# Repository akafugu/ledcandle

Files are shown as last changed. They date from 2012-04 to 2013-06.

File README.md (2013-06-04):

LED Candle Firmware & CAD files
--------------------------

Firmware and CAD filesfor the [Akafugu Flickering LED Candle](http://www.akafugu.jp/posts/products/ledcandle/)

The Akafugu LED Candle is an artificial candle that imitates the flickering of
a real candle. Use it in place of a real tea candle: It will fit
inside a tea candle casing or any holder made for tea candles.

It comes as a kit of easy to solder components, and is suitable for beginners
to soldering.

FEATURES:

* Randomly flickering LED: Imitates a candle
* Fits inside a tea candle casing
* Open Source Firmware (available at [GitHub](https://github.com/akafugu/ledcandle))
* Open Source Hardware: Eagle PCB design files available at GitHub.
* On-board ISP header for upgrading firmware

Firmware
--------

The Akafugu LED Candle uses an ATTiny13A microcontroller. The firmware is written for the
avr-gcc compiler.

See [here](http://www.akafugu.jp/posts/resources/avr-gcc/) for avr-gcc installation instructions.

Plug in ISP programmer into the ISP header, and in the directory 'firmware', do:

make fuse flash

An alternative firmware is available in the directory firmware_pwm, courtesy of madworm.
This firmware features a very different and slower flickering style.

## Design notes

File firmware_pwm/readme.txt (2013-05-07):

Works very well with the akafugu LED candle board.

Notes:
======

The FUSE settings of the AVR are different to the original from akafugu.
Probably as a consequence of the increased clock-speed of the internal
RC-oscillator, the AVR won't start after programming when using 5V.
It will run fine with 3.3V or the lithium battery.

This issue can be addressed in two ways:

* switch your ISP programmer to 3.3V
* add a small bypassing capacitor right across pins #4 and #8

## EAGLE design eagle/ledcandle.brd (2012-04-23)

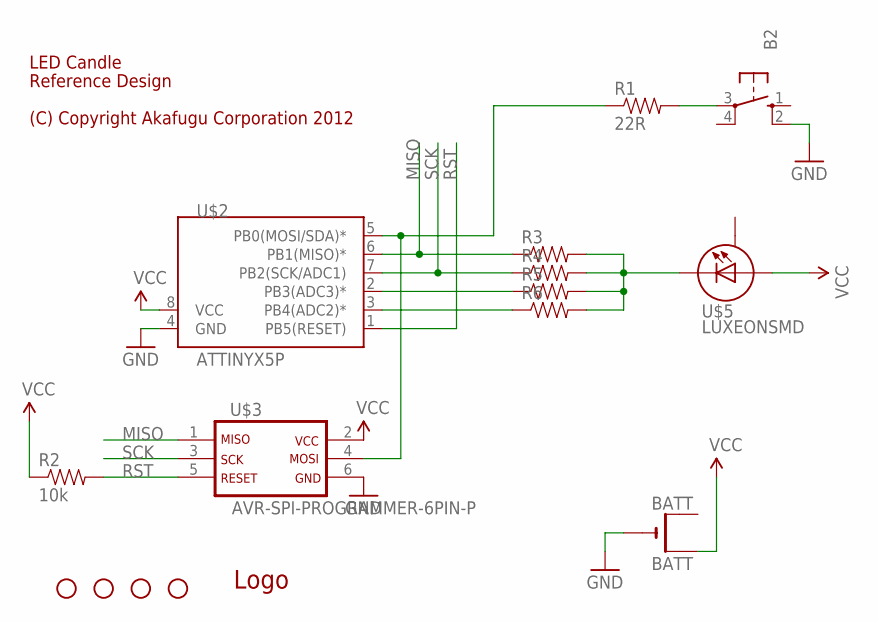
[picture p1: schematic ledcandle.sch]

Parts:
B2: 10-XX; B3F-10XX
BATT: BATT; CR2032-THM-PAD
JP1, JP2, JP3, JP4: STAND-OFF
R1: 22R; 1/6W-RES-OUTLINE
R2: 10k; 1/6W-RES-OUTLINE
R3, R4, R5, R6: RESISTOR-PTH-1/6W-OUTLINE; 1/6W-RES-OUTLINE
U$1: OSHW-LOGO-FILL
U$2: ATTINYX5P; DIL-8
U$3: AVR-SPI-PROGRAMMER-6PIN-P; 2X03
U$5: LUXEONSMD; LUXEON

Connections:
GND: B2.2 (S1), BATT.-, U$2.4 (GND), U$3.6
MISO: R3.1, U$2.6 (PB1(MISO)*), U$3.1
unnamed: R6.1, U$2.3 (PB4(ADC2)*)
unnamed: R3.2, R4.2, R5.2, R6.2, U$5.C
unnamed: R5.1, U$2.2 (PB3(ADC3)*)
unnamed: R1.1, U$2.5 (PB0(MOSI/SDA)*), U$3.4
RESET: B2.3, R1.2
RST: R2.2, U$2.1 (PB5(RESET)), U$3.5
SCK: R4.1, U$2.7 (PB2(SCK/ADC1)), U$3.3
VCC: BATT.+2 (+1), R2.1, U$2.8 (VCC), U$3.2, U$5.A

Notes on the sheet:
LED Candle
Reference Design
(C) Copyright Akafugu Corporation 2012

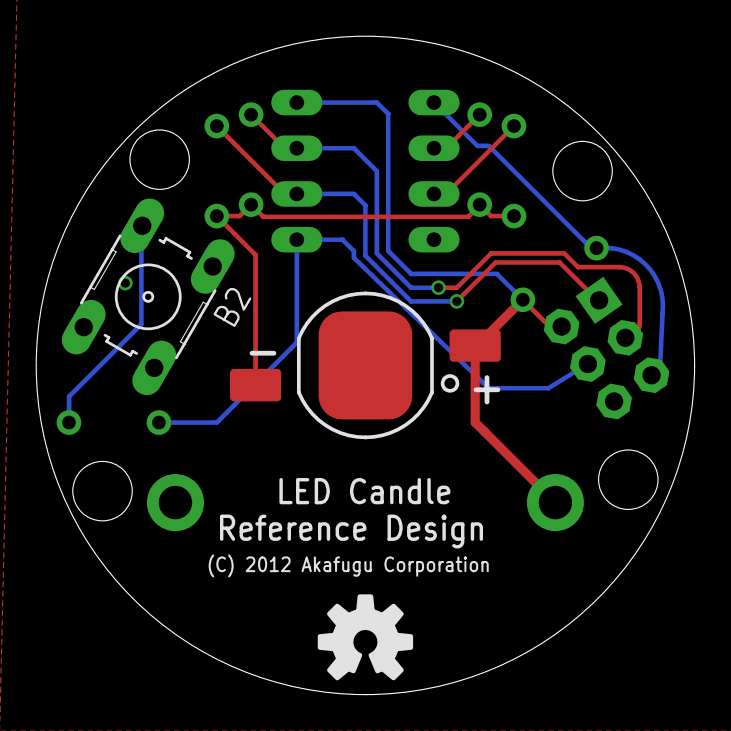
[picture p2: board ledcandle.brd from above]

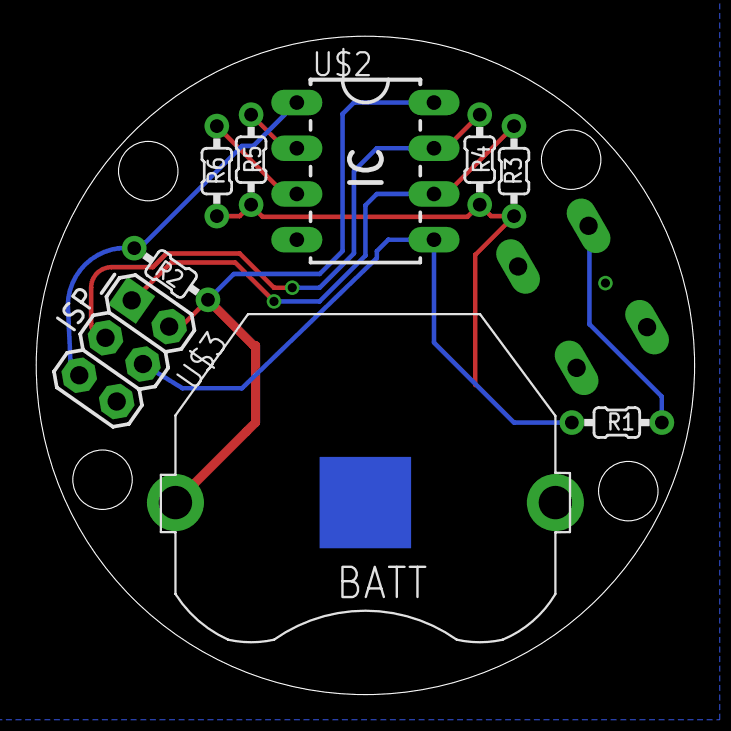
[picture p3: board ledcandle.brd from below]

Board: 2 copper layers, 36.6 x 36.6 mm, 16 parts (9 on the bottom side), 10 nets.

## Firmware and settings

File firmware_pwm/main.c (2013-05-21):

/*
 * Original firmware
 * =================
 *
 * Flickering LED Candle
 * (C) 2012 Akafugu Corporation
 *
 *
 * Alternative firmware with 8-bit PWM
 * ===================================
 *
 * 2013 - Robert Spitzenpfeil
 *
 *
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
 */

/*
 * Pinout:
 * PB0 (pin 5) - Button (INT0 interrupt)
 * PB1 (pin 6) - LED (PWM)
 * PB2 (pin 7) - LED
 * PB3 (pin 2) - LED
 * PB4 (pin 3) - LED
 * PB5 (pin 1) - Reset
 *
 * 1k resistor per pin. Suitable for running from a 3V CR2032 cell
 *
 *
 * Inspired by similar LED candle projects on Instructables:
 *
 * http://www.instructables.com/id/YAFLC-Yet-Another-Flickering-LED-Candle/
 * http://www.instructables.com/id/Realistic-Fire-Effect-with-Arduino-and-LEDs/
 *
 */

//#define DEBUG

#include <avr/io.h>
#include <avr/interrupt.h>
#include <avr/sleep.h>
#include <util/delay.h>
#include <stdbool.h>
#include "main.h"

// how long to stay on
uint16_t off_timer = ON_2H;

// minimum light-level
#define MIN_BRIGHTNESS 16

// random number seed (will give same flicker sequence each time)
uint32_t lfsr = 0xbeefcace;

volatile uint8_t brightness = 0; // not changed in an ISR, but prevent optimizer to throw it out
volatile uint8_t sleep_requested = 0;

int main(void)
{
	// Attiny13A fuse setting: -U lfuse:w:0x7A:m -U hfuse:w:0xFB:m
	//
	// set system-clock prescaler to 1/8
	// 4.8MHz RC-oscillator --> 600kHz system-clock
	CLKPR = _BV(CLKPCE);
	CLKPR = _BV(CLKPS1) | _BV(CLKPS0);

	// configure TIMER0
	TCCR0A = _BV(WGM01);	// set CTC mode
	TCCR0B = ( _BV(CS01) );	// set prescaler to 8
	// enable COMPA ISR
	TIMSK0 = _BV(OCIE0A);
	// set top value for TCNT0
	OCR0A = 10;		// just some start value

	// pull-up on for BUTTON_PIN
	PORT_OUT_REG |= _BV(BUTTON_PIN);
	// set port directions
	PORT_DIR_REG = PORT_DIR_MASK;
	
	// disable analog comparator to save power
	ACSR = _BV(ACD);

	// Pin change interrupt enabled
	// The actual pin will be activated later
	GIMSK |= _BV(PCIE);
		
	// globally enable interrupts
	// necessary to wake up from sleep via pin-change interrupt
	sei();

	fade(0,255,1);

	while (1) {
		// the flag 'sleep_requested' is set in the ISR: TIM0_COMPA_vect
		if(sleep_requested == 1) {
			do_sleep();
		}
		flicker();
	}
}

uint32_t rand(void)
{
	// http://en.wikipedia.org/wiki/Linear_feedback_shift_register
	// Galois LFSR: taps: 32 31 29 1; characteristic polynomial: x^32 + x^31 + x^29 + x + 1 
	lfsr = (lfsr >> 1) ^ (-(lfsr & 1u) & 0xD0000001u);
	return lfsr;
}

// Enter sleep mode: Wake on INT0 interrupt
void do_sleep(void)
{
	cli(); // turn all interrupts off, so we can be sure nothing gets disturbed here
	sleep_requested = 0;

	// now we want to make sure the button is not pressed and is stable (not bouncing)
	// switch bouncing is an unwanted wake-up source

	#ifdef DEBUG
		PORT_OUT_REG |= LED_MASK; // all ON - current source
	#else
		PORT_OUT_REG &= ~LED_MASK; // all ON - current sink
	#endif

	while( !(PORT_IN_REG & _BV(BUTTON_PIN)) ) { // while button is pressed (LOW)
		delay(500);
	}

	set_sleep_mode(SLEEP_MODE_PWR_DOWN);
	sleep_enable();

	sei();
	fade(255,0,1); // fade OUT after the button was released
	GIFR &= ~_BV(PCIF); // clear PC-interrupt flag - just to be safe
	PCMSK = PINC_MASK; // 'remove the safety' on the pin-change interrupt at the last possible moment
	sleep_cpu();
	sleep_disable();
	fade(0,255,1);	// wake up here again
}

// Interrupt signal PCINT0: On PB0 (PB2 for DEBUG, different board)
ISR(PCINT0_vect)
{
	PCMSK = 0; // clear PCINT-mask to disable pin-change interrupt
	GIFR |= _BV(PCIF); // clear PCIF
}

// Flicker by randomly setting pins PB1~PB4 on and off
void flicker(void)
{
	uint8_t flicker_brightness = (uint8_t)(rand()); // user lowermost 8 bits to set values for the LED brightness

	fade(brightness, MIN_BRIGHTNESS, (uint8_t)(rand() >> 30) ); // fade from current brightness down to MIN_BRIGHTNESS, random fade speed
	delay( (uint8_t)(rand() >> 24) ); // random delay
	fade(MIN_BRIGHTNESS, flicker_brightness, (uint8_t)(rand() >> 30) ); // fade from MIN_BRIGHTNESS to a random brightness, random fade speed
	delay( (uint8_t)(rand() >> 24) ); // random delay
}

ISR(TIM0_COMPA_vect)
{
	static uint16_t bitmask = 0b0000000000000001;
	static uint16_t sec_counter = 0;
	static uint16_t PWM_cycle_counter = 0;
	static uint16_t button_held_counter = 0;
	uint8_t OCR0A_next;

	// increase system-clock
	CLKPR = _BV(CLKPCE);	// set CLocK Prescaler Change Enable bit
	CLKPR = 0;		// set system-clock prescaler to 1 --> full 9.6MHz

	// Binary-weighted PWM generation - BEGIN

	if ( brightness & bitmask ) { // turn ON
		#ifdef DEBUG
			PORT_OUT_REG |= LED_MASK; // source current
		#else
			PORT_OUT_REG &= ~LED_MASK; // sink current
		#endif
	} else { // turn OFF
		#ifdef DEBUG
			PORT_OUT_REG &= ~LED_MASK;
		#else
			PORT_OUT_REG |= LED_MASK;
		#endif
	}

	OCR0A_next = bitmask; // the bitmask determines when the ISR is called next - intervals: 1, 2, 4, 8, 16, 32, 64, 128
	bitmask = bitmask << 1; // shift 1 bit to the left

	if (bitmask == _BV(9)) {
		bitmask = 0x0001;
		OCR0A_next = 2;
		PWM_cycle_counter++;
	}

	OCR0A = OCR0A_next;	// when to run next time
	TCNT0 = 0;		// clear timer to compensate for code runtime above
	TIFR0 = _BV(OCF0A);	// clear interrupt flag to kill any erroneously pending interrupt in the queue

	// PWM generation - END

	if (PWM_cycle_counter == 293) {	// count seconds
		sec_counter++;
		PWM_cycle_counter = 0;
	}

	if (PORT_IN_REG & _BV(BUTTON_PIN)) {	// button is not held
		button_held_counter = 0;
	} else {		// button is held
		button_held_counter++;
	}

	// time to go to sleep?
	if (off_timer != 0 && sec_counter >= off_timer) {
		sec_counter = 0;
		sleep_requested = 1;
	}
	// holding the button for 3 seconds turns the device off
	if (button_held_counter == 7032) {
		sec_counter = 0;
		sleep_requested = 1;
	}

	// decrease system-clock
	CLKPR = _BV(CLKPCE); // set 'CLocK Prescaler Change Enable'
	CLKPR = _BV(CLKPS1) | _BV(CLKPS0);	// set system-clock prescaler to 1/8 --> 4.8 MHz / 8 = 600kHz
}

void delay(uint16_t ms) {
	while(ms) {
		_delay_ms(1); // this function must be called with a compile-time CONST, otherwise it pulls in float-math (huge)
		ms--;
	}
}

void fade(uint8_t from, uint8_t to, uint8_t f_delay) {
	uint8_t counter;

	// I know the fade stops at (to-1).

	if(from <= to) {
		for(counter = from; counter < to; counter++) {
			brightness = counter;
			delay(f_delay);
		}
	}

	if(from > to) {
		for(counter = from; counter > to; counter--) {
			brightness = counter;
			delay(f_delay);
		}
	}
}

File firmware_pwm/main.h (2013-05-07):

#ifndef main_h
#define main_h

// defines for on time (in seconds)
#define ON_1H 3600
#define ON_2H 7200
#define ON_3H 10800
#define ON_4H 14400
#define ON_5h 18000

#ifdef DEBUG
	// A different dev-board was used to develop the firmware
	#define PORT_DIR_REG DDRB
	#define PORT_OUT_REG PORTB
	#define PORT_IN_REG PINB
	#define BUTTON_PIN PB2
	// LED sits on PB0
	#define LED_MASK 0b00000001
	// PB0 as output, rest input
	#define PORT_DIR_MASK 0b00000001
	// pin-change mask
	#define PINC_MASK 0b00000100
#else
	// Values for the original Akafugu LED candle hardware
	#define PORT_DIR_REG DDRB
	#define PORT_OUT_REG PORTB
	#define PORT_IN_REG PINB
	#define BUTTON_PIN PB0
	// LEDs sit on PB4...PB1
	#define LED_MASK 0b00011110
	// PB4...PB1 as output, rest input
	#define PORT_DIR_MASK 0b00011110
	// pin-change mask
	#define PINC_MASK 0b00000001
#endif

// not used, but nice to have
#define sbi(var, mask)   ((var) |= (uint8_t)(1 << mask))
#define cbi(var, mask)   ((var) &= (uint8_t)~(1 << mask))

int main(void); 
void fade(uint8_t from, uint8_t to, uint8_t f_delay) __attribute__ ((noinline));
void delay(uint16_t ms) __attribute__ ((noinline));
void flicker(void);
void do_sleep(void);
uint32_t rand(void) __attribute__ ((noinline));

#endif

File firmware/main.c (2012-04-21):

/*
 * Flickering LED Candle
 * (C) 2012 Akafugu Corporation
 *
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
 */

/*
 * Pinout:
 * PB0 (pin 5) - Button (INT0 interrupt)
 * PB1 (pin 6) - LED (PWM)
 * PB2 (pin 7) - LED
 * PB3 (pin 2) - LED
 * PB4 (pin 3) - LED
 * PB5 (pin 1) - Reset
 *
 * 1k resistor per pin. Suitable for running from a 3V CR2032 cell
 *
 *
 * Inspired by similar LED candle projects on Instructables:
 *
 * http://www.instructables.com/id/YAFLC-Yet-Another-Flickering-LED-Candle/
 * http://www.instructables.com/id/Realistic-Fire-Effect-with-Arduino-and-LEDs/
 *
 */

#define BUTTON_PORT PORTB
#define BUTTON_DDR  DDRB
#define BUTTON_PIN  PINB
#define BUTTON_BIT PB0

#include <avr/io.h>
#include <avr/interrupt.h>
#include <avr/sleep.h>
#include <util/delay.h>
#include <stdbool.h>

#define sbi(var, mask)   ((var) |= (uint8_t)(1 << mask))
#define cbi(var, mask)   ((var) &= (uint8_t)~(1 << mask))

// button control
volatile bool button_held = false;

// defines for on time (in seconds)
#define ON_1H 3600
#define ON_2H 7200
#define ON_3H 10800
#define ON_4H 14400
#define ON_5h 18000

// for counting seconds
volatile uint16_t int_counter;
volatile uint16_t sec_counter;

// how long to stay on
volatile uint16_t off_timer = ON_2H;

// for hold to turn off feature
volatile uint16_t button_held_counter; // how long has button been held?
volatile bool off_flag = false; // has the button been held long enough to turn off?

// for flickering intensity
volatile bool fast_flicker = true;

void led_off(void)
{
	PORTB = 0xff;
	DDRB = 0b11111110;
}

void led_on(void)
{
	PORTB = 0x1; // keep pull-up for button set
	DDRB = 0b11111110;
}

// random number seed (will give same flicker sequence each time)
volatile uint32_t lfsr = 0xbeefcace;

uint32_t rand(void)
{
	// http://en.wikipedia.org/wiki/Linear_feedback_shift_register
	// Galois LFSR: taps: 32 31 29 1; characteristic polynomial: x^32 + x^31 + x^29 + x + 1 */
  	lfsr = (lfsr >> 1) ^ (-(lfsr & 1u) & 0xD0000001u);
	return lfsr;
}

// Enter sleep mode: Wake on INT0 interrupt
void do_sleep(void)
{
	led_off();

	GIMSK |= (1<<PCIE); // Pin change interrupt enabled
	PCMSK |= 1<<PCINT0;

	sei();
	set_sleep_mode(_BV(SM1)); // Power down sleep mode (sets MCUCR)
	sleep_mode();

	off_timer = ON_2H;
}

// Interrupt signal PCINT0: On PB0
ISR (PCINT0_vect)
{
	cli();
}

// Flicker by randomly setting pins PB1~PB4 on and off
void flicker(void)
{
	uint32_t r;
	uint8_t temp;

	// Inititalize timer
	TCCR0B = (1<<CS01); // Set Prescaler to clk/8 : 1 click = aprox 2us (using 4.6MHz internal clock)
	TIMSK0 |= (1<<TOIE0); // Enable Overflow Interrupt Enable
	TCNT0 = 0; // Initialize counter

	// LED off
	PORTB = 0xff;
	// PB0 as input
	DDRB = 0b11111110;
	// enable PB0 pull-up
	BUTTON_PORT |= _BV(BUTTON_BIT);

	GIMSK |= (1<<PCIE); // Pin change interrupt enabled
	PCMSK |= 1<<PCINT0;

	while(1)
	{
		r = rand();

		if (off_flag) {
			led_off();
		}
		else {
			temp = (uint8_t)r; // use lowermost 8 bits to set values for the LED pins

			// set PB1~PB4 according to value of temp
			if (temp & 1) { // off
				cbi(DDRB, PB1);
				sbi(PORTB, PB1);
			}
			else { // on
				sbi(DDRB, PB1);
				cbi(PORTB, PB1);
			}

			if (temp & (1<<1)) { // off
				cbi(DDRB, PB2);
				sbi(PORTB, PB2);
			}
			else { // on
				sbi(DDRB, PB2);
				cbi(PORTB, PB2);
			}
			
			if (fast_flicker) {
				if (temp & (1<<2)) { // off
					cbi(DDRB, PB3);
					sbi(PORTB, PB3);
				}
				else { // on
					sbi(DDRB, PB3);
					cbi(PORTB, PB3);
				}
			}
			else {
				sbi(DDRB, PB3);
				cbi(PORTB, PB3);
			}

			// Keep at least one pin on at all times to keep LED from turning off completely
			sbi(DDRB, PB4);
			cbi(PORTB, PB4);
		}

		// Use top byte to control delay between each intensity change
		// Tweaking these numbers will affect the speed of the flickering
		temp = (uint8_t) (r >> 24);
		_delay_loop_2(temp<<7);
	} 
}

// 1 click = aprox 2us*8 = 16us
// interrupt runs every 256 clicks = every 4096 us = 0.004096 seconds
// 244 interrupts = aprox 1 second ideally
// actual value tweaked to match CPU load
ISR(TIM0_OVF_vect)
{
	if (++int_counter == 285) { // count seconds
		sec_counter++;
		int_counter = 0;
	}
	
	if (BUTTON_PIN & _BV(BUTTON_BIT)) { // button is not held
		if (button_held_counter > 0) { // button up detected
			fast_flicker = !fast_flicker; 
		}

		button_held = false;
		button_held_counter = 0;
	}
	else { // button is held
		button_held = true;
		button_held_counter++;
	}

	// time to go to sleep?
	if (off_timer != 0 && sec_counter >= off_timer && !button_held) {
		sec_counter = 0;
		off_flag = false;
		button_held_counter = 0;
		do_sleep();
		return;
	}
	
	// holding the button for 3 seconds turns the device off
	if (button_held_counter == 570) {
		off_flag = true;
		return;
	}
	
	// when off flag is set, wait for key up to go to sleep (otherwise the interrupt pin will wake the device up again)
	if (off_flag && !button_held) {
		off_flag = false;
		do_sleep();
	}
}

void main(void) __attribute__ ((noreturn));

void main(void)
{
	sei();
	flicker();
	while(1) {}
}

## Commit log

2012-04-23 Added eagle CAD files
    [ledcandle.brd, ledcandle.sch]
2013-04-25 First doodles for my alternative PWM-firmware.
2013-04-25 So far so good. Need button debouncing!
2013-04-26 Added crude anti-bounce check for the button in do_sleep().
2013-04-26 There is a weird not-waking-up issue...
    [main.c]
2013-04-26 Replaced fade_in() and fade_out() with fade(from,to);
    [main.c, main.h]
2013-05-07 Fixed a typo in main.c
    [main.c]
2013-05-07 Last adjustmenst, so the PWM firmware runs on the real hardware as well.
2013-05-07 PC-interrupt enabled later. Fixed hangs after button press before sleep.
    [main.c]

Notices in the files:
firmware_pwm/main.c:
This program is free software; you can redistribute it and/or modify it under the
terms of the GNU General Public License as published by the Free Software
